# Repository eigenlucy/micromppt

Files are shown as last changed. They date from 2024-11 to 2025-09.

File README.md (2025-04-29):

# [micromppt](https://eigenlucy.github.io/projects/micromppt/)

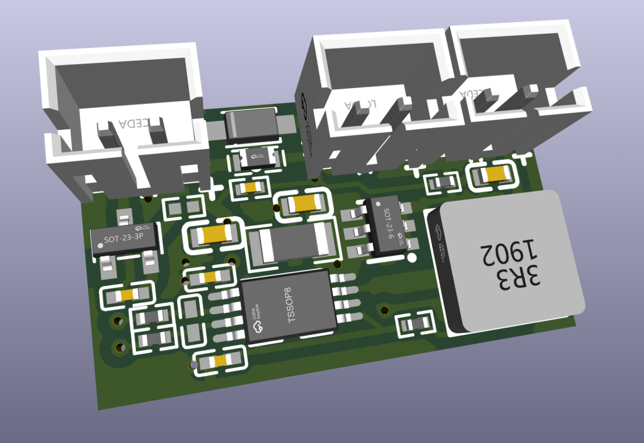
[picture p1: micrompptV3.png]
Micromppt V3


SPV1040 Based 5W MPPT Boost Charger With Autonomous Perturb-and-Observe Set Point Adjustment

Tiny, versatile, high efficiency solar charging, designed with Meshtastic clients in mind

This release has been configured for single cell lipo charging, and includes an [XB3306](https://www.lcsc.com/datasheet/lcsc_datasheet_2106062206_XySemi-XB3306D_C2759992.pdf) lithium battery protection circuit. I have tested this converter with avariety of cell chemistries, as well as supercapacitors, and I will release a more minimal SPV1040 package in the upcoming week with configuration guidelines to for a more general purpose multichemistry solar charging module. [See the project page on my website for more configuration guidelines, panel recommendations, and ordering info (WIP)](https://eigenlucy.github.io/projects/micromppt/).

Built with atopile and KICAD 9. See my [atopile usage guide](/ATO_USAGE.md) for help installing and using atopile

TO DO:
- Split the project into a base micromppt module and a number of input and output projection modules
- Solve Vout divider with assertions, add cutoff and BPC for other chemistries

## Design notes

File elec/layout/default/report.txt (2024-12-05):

Warning: Width correction constrained.  The width correction value must be in the range of [0.000001 mm; 0.199999 mm] for the current design rules.
Plotted to '/home/lucy/Documents/atopile/micromppt/gerbers/micromppt-F_Cu.gbr'.
Plotted to '/home/lucy/Documents/atopile/micromppt/gerbers/micromppt-B_Cu.gbr'.
Plotted to '/home/lucy/Documents/atopile/micromppt/gerbers/micromppt-F_Paste.gbr'.
Plotted to '/home/lucy/Documents/atopile/micromppt/gerbers/micromppt-B_Paste.gbr'.
Plotted to '/home/lucy/Documents/atopile/micromppt/gerbers/micromppt-F_Silkscreen.gbr'.
Plotted to '/home/lucy/Documents/atopile/micromppt/gerbers/micromppt-B_Silkscreen.gbr'.
Plotted to '/home/lucy/Documents/atopile/micromppt/gerbers/micromppt-F_Mask.gbr'.
Plotted to '/home/lucy/Documents/atopile/micromppt/gerbers/micromppt-B_Mask.gbr'.
Plotted to '/home/lucy/Documents/atopile/micromppt/gerbers/micromppt-Edge_Cuts.gbr'.
Created Gerber job file '/home/lucy/Documents/atopile/micromppt/gerbers/micromppt-job.gbrjob'.
Info: Done.

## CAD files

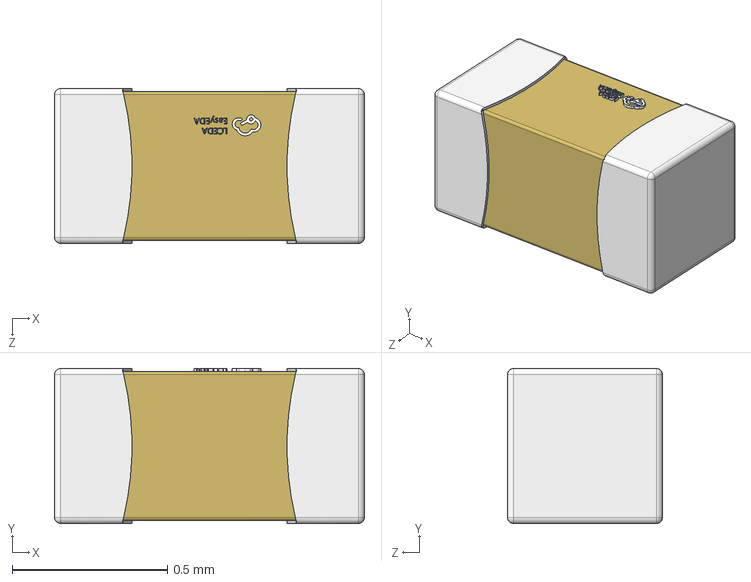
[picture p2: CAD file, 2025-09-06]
elec/src/parts/CCTC_TCC0402X7R102M500AT/C0402_L1.0-W0.5-H0.5.step
1.00 x 0.5 x 0.5 mm

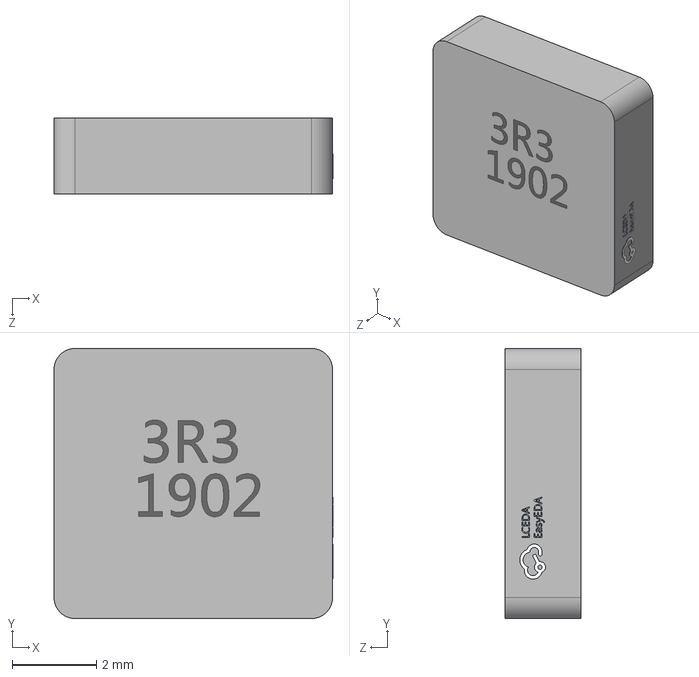
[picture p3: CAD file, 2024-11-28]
elec/src/parts/Coilcraft_XAL6060_103MEC/IND-SMD_L6.6-W6.4-H2.9.step
6.61 x 6.40 x 1.81 mm

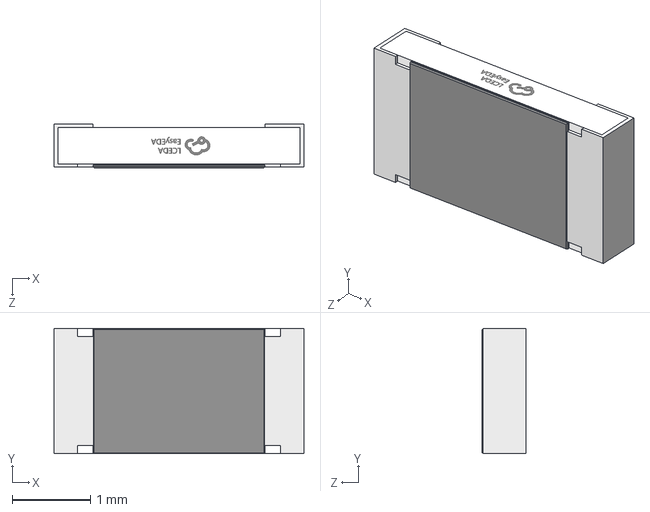
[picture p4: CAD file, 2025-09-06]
elec/src/parts/FOJAN_FRM121WFR010TM/R1206_L3.2-W1.6-H0.6.step
3.20 x 1.60 x 0.56 mm

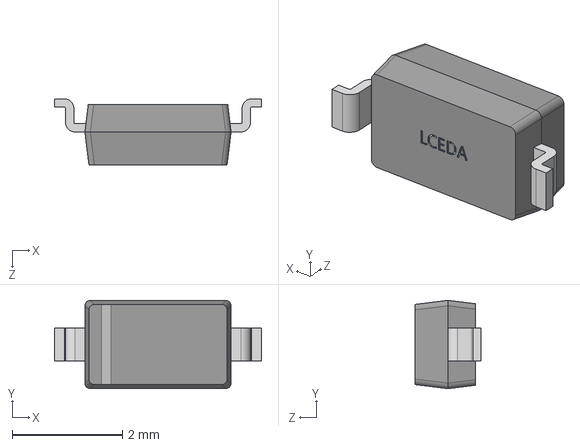
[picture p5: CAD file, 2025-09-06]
elec/src/parts/GOODWORK_B5819W/SOD-123F_L2.7-W1.6-LS3.8-RD-1.STEP
3.75 x 1.60 x 1.20 mm

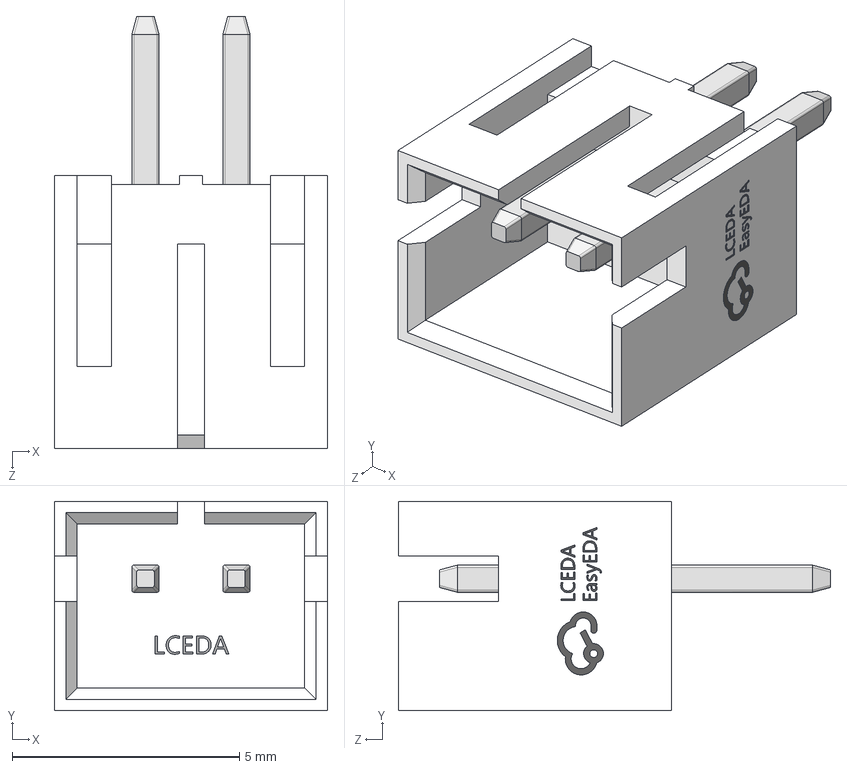
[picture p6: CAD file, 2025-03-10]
elec/src/parts/JST_Sales_America_B2B_PH_K_S_LF__SN/CONN-TH_PH2.00-LI-2P.step
6.00 x 4.60 x 9.50 mm

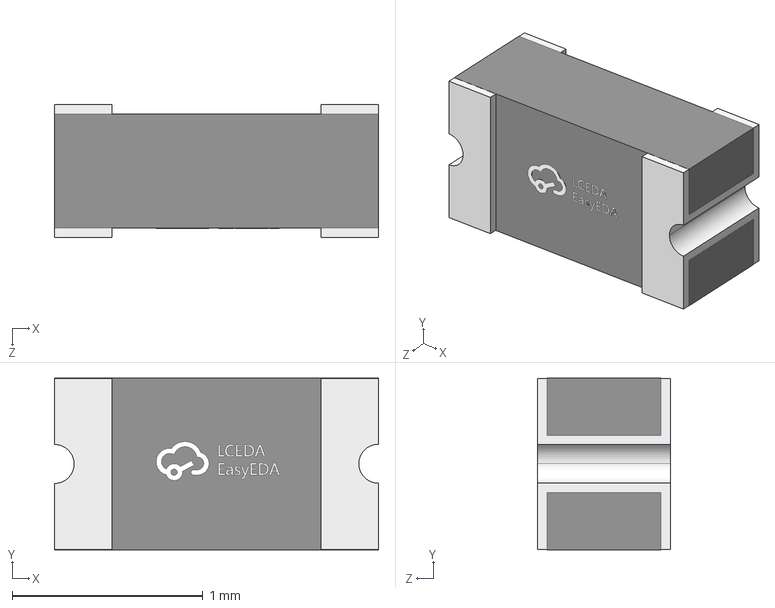
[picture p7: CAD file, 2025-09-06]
elec/src/parts/Littelfuse_0603L150SLYR/F0603_L1.7-W0.9-H0.7.step
1.70 x 0.9 x 0.7 mm

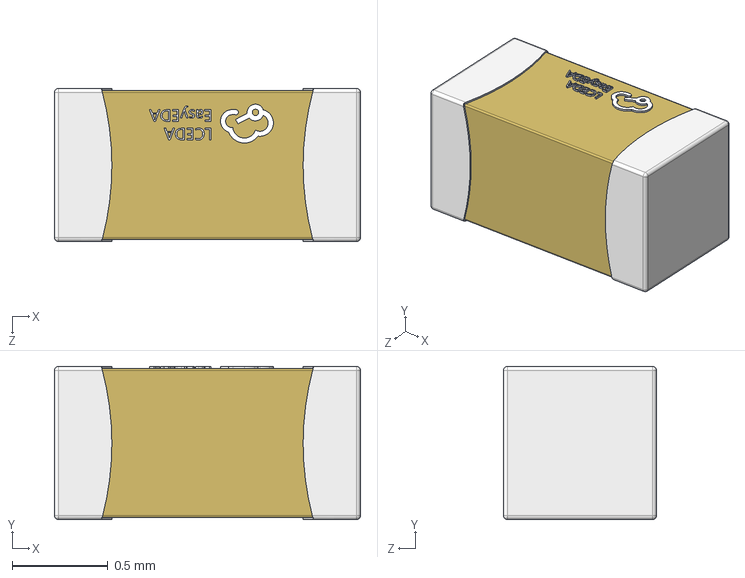
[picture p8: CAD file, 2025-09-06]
elec/src/parts/Samsung_Electro_Mechanics_CL10A106MQ8NNNC/C0603_L1.6-W0.8-H0.8.step
1.60 x 0.8 x 0.8 mm

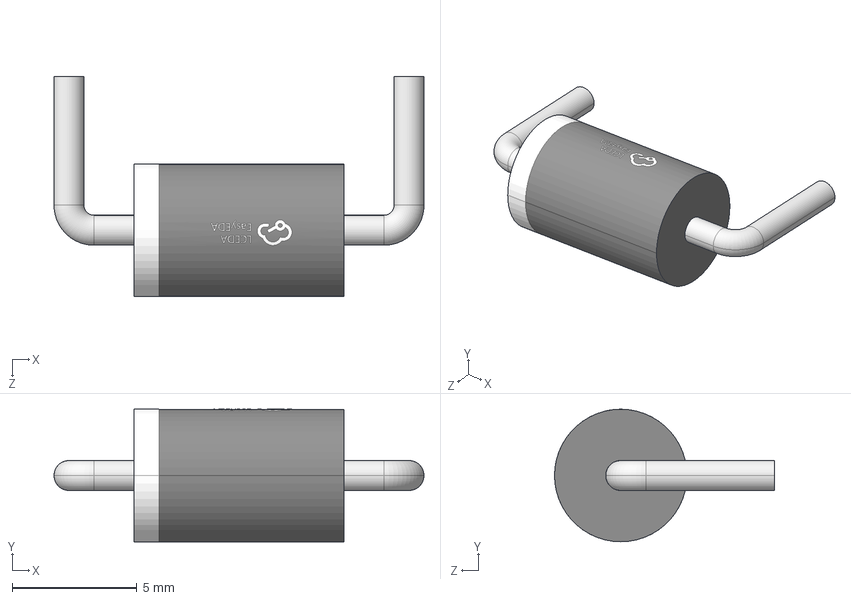
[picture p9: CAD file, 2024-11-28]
elec/src/parts/STMicroelectronics_1N5908/DO-201AD_D5.3-L8.4-P13.6.step
14.8 x 5.30 x 8.80 mm

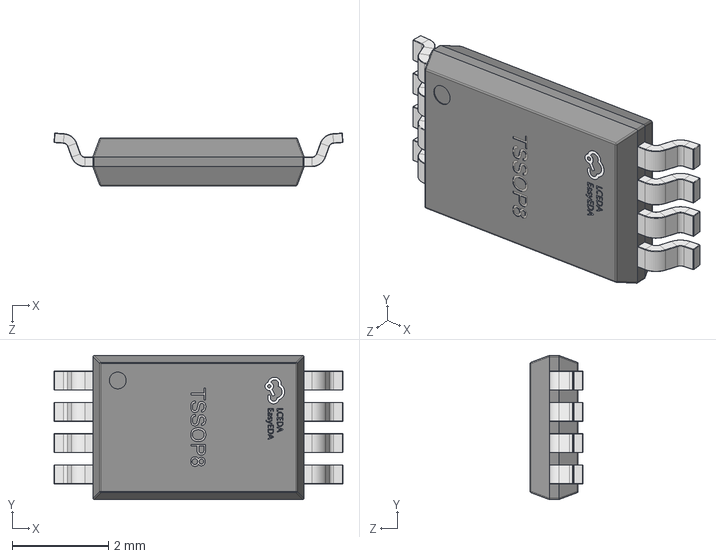
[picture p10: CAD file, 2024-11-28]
elec/src/parts/STMicroelectronics_SPV1040T/TSSOP-8_L3.0-W4.4-H1.0-LS6.4-P0.65.step
6.01 x 3.00 x 1.10 mm

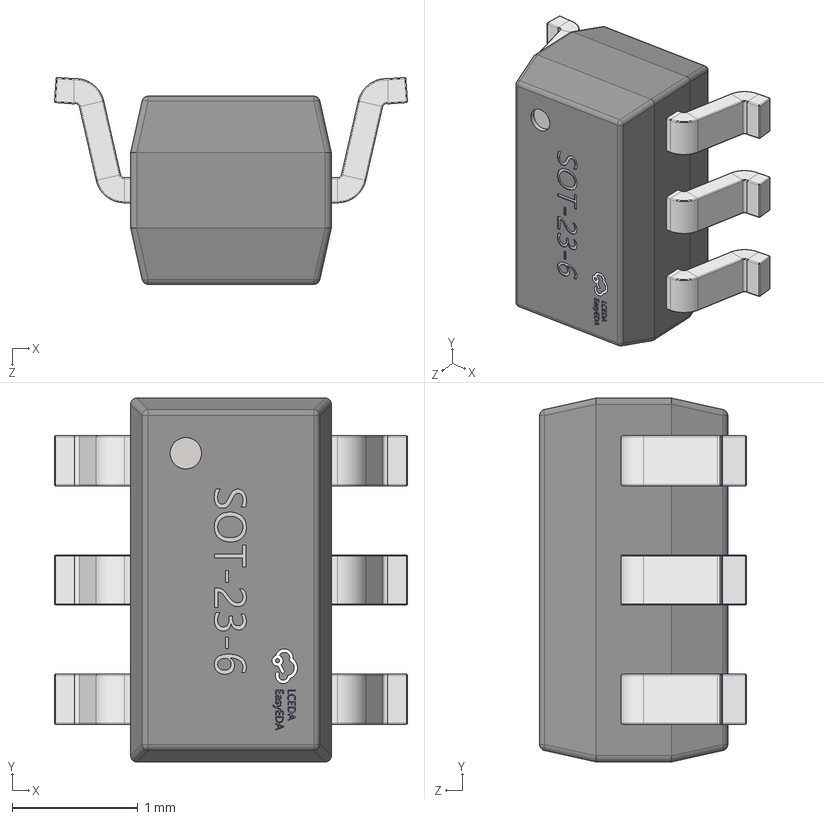
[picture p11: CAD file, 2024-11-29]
elec/src/parts/TECH_PUBLIC_SRV05_4_P_T7/SOT-23-6_L2.9-W1.6-H1.5-LS2.8-P0.95.step
2.81 x 2.90 x 1.65 mm

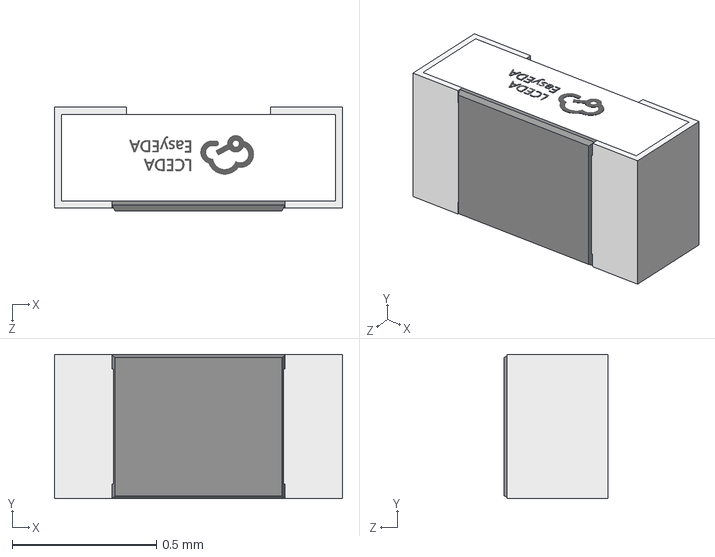
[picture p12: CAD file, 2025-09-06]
elec/src/parts/UNI_ROYAL_0402WGF1000TCE/R0402_L1.0-W0.5-H0.4.step
1.00 x 0.501 x 0.36 mm

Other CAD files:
elec/src/parts/XySemi_XB3306D/SOT-23-3P_L2.9-W1.3-H1.0-LS2.4-P0.95.step

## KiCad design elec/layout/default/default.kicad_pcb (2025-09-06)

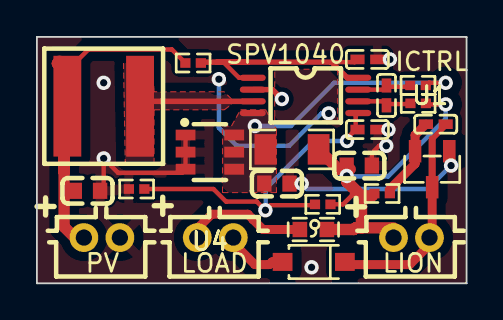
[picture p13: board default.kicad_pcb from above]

Board: 2 copper layers, 23.9 x 13.7 mm, 23 parts (0 on the bottom side), 13 nets.

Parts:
C2: 4.7µF ±10% 16V X5R; C0603
C3: 10µF ±20% 6.3V X5R; C0603
C4: 100nF ±10% 16V X7R; C0402
C5: 1nF ±20% 50V X7R; C0402
C6: 1µF ±10% 25V X5R; C0402
D1: SOD-123F_L2.7-W1.6-LS3.8-RD-1
F1: F0603
R1: 1MΩ ±1% 62.5mW; R0402
R2: 390kΩ ±1% 62.5mW; R0402
R3, R4, R5: 1kΩ ±1% 62.5mW; R0402
R6: 10mΩ ±1% 1W; R1206
U1: TSSOP-8_L4.4-W3.0-P0.65-LS6.4-BL
U2: 100nF ±10% 16V X7R; C0402
U3: IND-SMD_L6.6-W6.4
U4: SOT-23-6_L2.9-W1.6-P0.95-LS2.8-BR
U5: 10µF ±20% 6.3V X5R; C0603
U6: 10kΩ ±1% 62.5mW; R0402
U7, U8, U10: CONN-TH_B2B-PH-K-S
U9: SOT-23-3_L2.9-W1.3-P1.90-LS2.4-BR

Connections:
ICTRL_MINUS: C6.2, R5.1, U1.6
ICTRL_PLUS: C6.1, R4.1, U1.7
LX: U1.3, U3.2
MPP_SET: C4.1, R3.2, U1.1, U1.8
VCTRL: C5.1, R1.2, R2.1, U1.5
VDD: U2.1, U6.1, U9.2
VOUT: C2.1, R4.2, R6.1, U1.4, U4.4, U4.5, U4.6
Vbat: C3.1, F1.1, R1.1, R5.2, R6.2, U6.2, U7.1
Vbatr-GND: D1.1, U2.2, U7.2, U9.3
Vpv: R3.1, U3.1, U5.1, U8.1
_1: F1.2, U10.1
anode: D1.2, U10.2
power_shim-GND: C2.2, C3.2, C4.2, C5.2, R2.2, U1.2, U4.1, U4.2, U4.3, U5.2, U8.2, U9.1

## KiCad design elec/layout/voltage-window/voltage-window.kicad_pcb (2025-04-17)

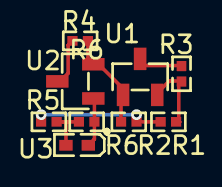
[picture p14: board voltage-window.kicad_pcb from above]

Board: 2 copper layers, 9 parts (0 on the bottom side), 7 nets.

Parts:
R1, R2, R3, R4, R5, R6: 10kΩ ±1% 62.5mW; R0402-56259e
U1, U2: SOT-23-3_L2.9-W1.3-P1.90-LS2.4-BR-688f29
U3: LED0402-R-RD-049f90

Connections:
A: R3.2, U1.3
K: R2.2, R4.1, U1.1, U2.2
OUT: R6.2, U2.1, U3.2
REF: R1.2, R3.1, U1.2
anode: R5.2, R6.1, U3.1
gnd: R4.2, U2.3
hv: R1.1, R2.1, R5.1

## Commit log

2024-11-29 pcb v1
    [micromppt.kicad_pcb]
2024-11-29 double squiggle
    [micromppt.kicad_pcb]
2024-12-05 pcb update and actions retry
    [micromppt-B_Cu.gbr, micromppt-B_Mask.gbr, micromppt-B_Paste.gbr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]
2024-12-08 removed extra build folders
    [micromppt-B_Cu.gbr, micromppt-B_Mask.gbr, micromppt-B_Paste.gbr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]
2025-01-10 connected c3/r1
    [micromppt.kicad_pcb]
2025-02-06 fixed unconnected vout feedback pin
    [micromppt.kicad_pcb]
2025-02-06 MICROMPPT V2
    [micromppt.kicad_pcb]
2025-02-06 built with ato v3, MICROMPPT V2 order
    [default.kicad_pcb, micromppt.kicad_pcb]
2025-02-08 v3 update
    [micromppt.kicad_pcb]
2025-03-08 Revert "v3 update"
    This reverts commit 3d2f1a32cb7bdd8d1440f52d8c2b71f7bcce05a5.
    [micromppt.kicad_pcb]
2025-03-08 fixed :woozy:
    [micromppt.kicad_pcb]
2025-03-09 Micromppt V3 (fr this time)
    [default.kicad_pcb, micromppt.kicad_pcb]
2025-03-09 Micromppt V3 (fr this time) x2
    [micromppt.kicad_pcb]
2025-03-10 Micromppt V3 added githash
    [micromppt.kicad_pcb]
2025-03-10 new connector
    [micromppt.kicad_pcb]
2025-04-08 micromppt V3
    [micromppt.kicad_pcb]
2025-04-09 built with ato V3!
    [micromppt.kicad_pcb]
2025-04-09 fixed .github/workflows/ci.yml and set github actions versions to v4
    [micromppt.kicad_pcb]
2025-04-15 compiled with v4
    [default.kicad_pcb]
2025-04-16 changed layouts to original layout folder name, fixed layout syncing
    [default.kicad_pcb, micromppt.kicad_pcb]
2025-04-16 added voltage window monitor
    [micromppt.kicad_pcb, tl431-ovp.kicad_pcb, voltage-window.kicad_pcb]
2025-04-19 ready for publishing on the ato repo
    [micromppt.kicad_pcb]
2025-04-22 added load output and BPC
    [micromppt.kicad_pcb]
2025-04-22 reran DRC
    [micromppt.kicad_pcb]
2025-04-22 changed Vout set to 4.2
    [micromppt.kicad_pcb]
2025-04-22 added load PTC, fixed githash
    [default.kicad_pcb, micromppt.kicad_pcb]
2025-04-22 rebuilt, added picture to readme, ato usage guidelines
    [micromppt.kicad_pcb]
2025-04-22 added graphics
    [micromppt.kicad_pcb, template_40x40.dxf, template_outline.dxf]
2025-08-28 building with 0.11.6
    [C0402_L1.0-W0.5-H0.5.step, C0603_L1.6-W0.8-H0.8.step, CONN-TH_PH2.00-LI-2P.step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]
2025-08-28 updated files, layout looked unaltered
    [default.kicad_pcb, default.kicad_sch, template_40x40.dxf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]
2025-09-06 update! works with current ato version
    [default.kicad_pcb]
2025-09-06 update! works with current ato version. reran DRC
    [default.kicad_pcb]
